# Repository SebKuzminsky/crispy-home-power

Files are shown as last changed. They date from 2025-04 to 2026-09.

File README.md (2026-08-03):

# Introduction

Project goals:
- When the PV system generates more energy than my house uses, store excess in batteries.
- When the house needs more energy that the PV system generates, supply from batteries.

This wants an "AC Coupled storage system".

Storing into batteries is easy, use an AC powered battery charger with
current control to charge the battery bank off the regular house AC.

How to supply from batteries?
- Large current-controlled micro-inverter?
- Multiple smaller micro-inverters, turn on/off as needed?

# Batteries

Manufacturer: American Battery Solutions

Product line: Alliance

Model: E48-2.0

Cell connections: 14S 8P

## Wire harness

Net      | Harness pin | Wire color
-------- | ----------- | ----------
Ign Low  | 2           | Blue (short to BAT- to ignite the battery)
CAN+ In  | 10          | Orange
CAN- In  | 9           | Black
CAN- Out | 7           | Purple
CAN+ Out | 6           | Gray

## CAN

Lots of good info in the Alliance User Manual.

There's an app in the `battery/` directory that controls the mode
and reports telemetry.

The modules collaborate over CAN to charge the low modules and discharge
the high modules in the expected way.  The following scope trace shows
the terminal voltage of three modules connected via CAN but not connected
via their high-voltage terminals.

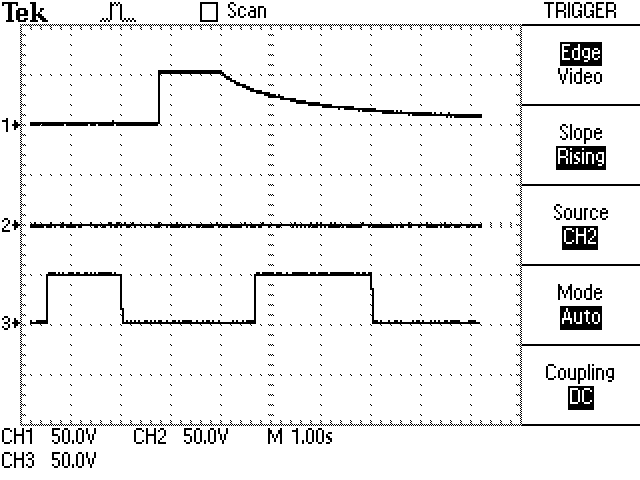
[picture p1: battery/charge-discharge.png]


- module on probe 1: ~51V
- module on probe 2: ~50V
- module on probe 3: ~48V

1. The pack starts out in "None" mode, where no modules are connected to the HV bus
2. I command the pack to Charge mode; the lowest-voltage module (on probe 3) enables its FET and connects to its HV terminals to receive charge.  The higher-voltage modules leave their FETs disabled and remain disconnected from the HV bus.
3. I command the pack to Drive/Discharge mode; the low module that was charging disconnects, and a second or so later the highest-voltage module (on probe 1) enables its FET and connects to the HV bus to discharge.
4. Switching back to Charge mode disables the high module and re-enables the low module.

Note that the middle module (50V, on probe 2) was never enabled in this
test.  If the low module had charged up to ~50V it would have enabled
during Charge mode, and if the high module had discharged down to ~50V
it would have enabled during Discharge/Drive mode.

```
CAN ID 0x502: `HOST_BatteryRequest`
    Payload: `HOST_stateRequest`, 1 byte
        0x00: None
        0x01: Drive/Discharge (power output)
        0x02: Charge (power input)
        0x03: Sleep
    Send this packet at 1 Hz
```

To ignite the battery from Linux over CAN and put it into Drive mode:
```
$ sudo ip link set can0 down
$ sudo ip link set can0 up type can bitrate 500000
$ while true; do cansend can0 '502#01.00'; sleep 1; done
```

To ignite the battery and put it into Charge mode, which makes it request
charge from the DeltaQ charger if it sees its CAN heartbeat:
```
$ while true; do cansend can0 '502#02.00'; sleep 1; done
```

To capture a CAN packet log:
```
$ candump -t a -l -f battery.candump can0
```

To replay a captured candump packet log:
```
$ sudo modprobe vcan
$ sudo ip link add dev vcan0 type vcan
$ sudo ip link set vcan0 up
$ canplayer -I battery.candump vcan0=can0
```

## Misc

Short the `IGN Low` pin to `BATT-` i think, and if the pack has
enough charge to boot the internal bms it'll energize `BATT+`.

Nathaniel says: I had one pack never shutoff after I turned it on with
an ignition signal, which is the main reason I no longer want to use
the pack BMS.

The HV terminals are tin-plated copper, with M8x1.25 thread, and should
be torqued to no more than 9Nm.

# Charger

Delta-Q
- Model: ICL 1500-058v
- Part number: 943-0016

## CAN

The one i have runs CAN at 500 kbps and uses different CAN packets than
what's in the docs.

CAN-H is blue
CAN-L is yellow

This makes it charge at 50 V, 2 A:
```
$ sudo ip link set can0 down
$ sudo ip link set can0 up type can bitrate 500000
$ while : ; do cansend can0 '30a#00.00.00.02.00.32.80.01'; cansend can0 '20a#00.31.01.00.32.20.00.01' ; sleep 1 ; done
```

The charger gets hot after a few minutes at higher current, but eventually
the fan comes on and cools it down.

# Inverters

I want a programmable inverter so I can tell it how much power to push
from the batteries to the home grid.

48V in, 240V split phase out

Bought a Victron inverter, model name "Phoenix". 48 V DC input, 120 VAC
output. 850 W continuous at 40°C, 2200W peak.

<https://www.victronenergy.com/inverters/phoenix-inverter-vedirect-250va-800va>

Works with an app on my phone, or you can get basic telemetry from a serial port.
`$ tio -b 19200 /dev/serial/by-id/usb-VictronEnergy_BV_VE_Direct_cable_VEAD75OS-if00-port0`

## Grid-forming

Grid-forming inverters supply voltage and frequency support to the grid,
as well as power.  This is needed for black start (bringing up the grid
after an outage).  Different modes of operation, such as: droop control,
virtual synchronous machine, hierachichal control, etc.

- PowerFlex 755T from Rockwell Automation
- Sunny Island from SMA Solar Technology
- PowerStore from ABB
- GridMaster from Ideal Power
- Victron Inverter Smart 48/2000, 230 VAC output

## Grid-following

Grid-following: supplies power, but must receive voltage and frequency from the grid.

## Misc info, open questions

Good info:
- <https://energycentral.com/c/iu/grid-forming-vs-grid-following>
- (terrible presentation) <https://www.youtube.com/watch?v=zWj21MMHPJc>
- <https://www.youtube.com/watch?v=RKQo9metcpU>

Some inverters can be both grid-forming and grid-following?

connecting inverters in parallel?  They must be grid-following, except
maybe one that "supplies voltage and frequency"?

Scenarios:
- grid tied
- grid tied system responds to grid disconnect
- island/off-grid (are these synonymous?)
- island reconnects to the grid
- black start

microgrids, islanded grids, large-scale grids

how does the enphase battery connect to the microgrid?  Does it go into the Combiner?

## Inverter Options

The internet thinks:
- "Enphase uses microinverters on their battery systems. They just stack them together."
- "With AC PV, the best options to power the entire main panel are EG4 18kPV, Midnite The One, or the Sol-Ark 15k. If you need more inverter, then parallel a 2nd or 3rd ..." <https://diysolarforum.com/threads/add-batteries-to-existing-solar-array-with-enphase-microinverters-and-iq-combiner.91153/post-1210119>

Inverters:
- Enphase M215/M250
    - <https://enphase.com/store/microinverters/legacy/m250-microinverter-kit>
- Enphase IQ8X-BATT
    - <https://enphase.com/download/iq8x-bat-microinverter-data-sheet>
    - Needs 52.5 VDC to start?
- Enphase IQ8+
    - runs on 16–58 V DC input
- Schneider Conext XW+ 6848
    - discontinuesd
- SunnyBoy
- Northern Electric BDM-600X
    - <https://northernep.com/downloads/technical-sheet/BDM-600X-Microinverter.pdf>

# Links & info

## Enphase Sunlight Backup

This is an Enphase design that keeps "limited loads" running when the
grid goes down, without battery storage.

- solar panels
- IQ8 micro-inverters with IQ8 cabling (this works with or without the grid when the needed additional equipment is present)
- IQ Combiner (includes IQ Gateway, solar production CT, 2 consumption CTs, enphase wireless comm kit)
- IQ System Controller (disconnects from the grid during outage)
- System shutdown switch
- Load center/subpanel (this is a subpanel that stays powered during outage)

## Misc

Probably do this: <https://university.enphase.com/?ccode=US&lang=en>

DIY Solar folks brainstorming a system very similar to what i want:
<https://diysolarforum.com/threads/adding-an-ess-to-enphase-enlighten-system.42737/>

<https://diysolarforum.com/threads/adding-diy-batteries-to-enphase-grid-tie-system.39487/>

<https://diysolarforum.com/threads/do-you-need-a-subscription-or-gateway-to-view-enphase-micro-inverter-data.92441/>

<https://diysolarforum.com/threads/using-solar-micro-inverters-with-batteries-instead-of-panels.8353/>

Enphase design guides: <https://enphase.com/installers/training/getting-started/design>

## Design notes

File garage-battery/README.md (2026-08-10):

This project is made from five parts:
1. Varta batteries
2. Victon inverter
3. Delta-Q charger (AC powered)
4. Enphase PV system
5. A Pi running the software in this repo

The batteries power the inverter, and the inverter powers a couple
of extension cords in the garage. The load is a fridge and a freezer,
the draw is about 200 W to 400 W.

# Software

The software in this repo monitors the SoC of the Varta batteries and
tries to keep them charged, using excess power from the PV array ideally
but falling back to grid AC power when needed.

## Varta Monitor

The Varta monitor looks at the Varta Master info, specifically the state
of charge and the charge request current.

## PV Monitor

The PV Monitor reads data from the Enphase Envoy via local Wifi (no
clown computing). Specifically we're looking to see if the PV system is
over-generating so we're exporting power to the grid.

## Control logic

The controller looks at the information gathered by the Varta Monitor
and the PV Monitor.  If the PV system is over-generating, we try to
divert this power to the batteries.

The Controller manages some internal configuration variables:
* minimum SoC: Take action when the batteries get below this.
* max SoC: Do not charge the batteries above this.
* charge current: Try to charge the batteries at this rate.

The Control logic works like this:

- When the house is generating excess power we set min SoC to 75%, max
  SoC to 80%, and "available current" sufficient to absorb most of the
  exported power.

- When there is no power being exported we set a min SoC of 20%, max
  SoC of 25%, and "available current" to infinity.

If the battery SoC is above the max SoC, we request the Charger to turn off.

If the battery SoC is below the min SoC, we request the Charger to turn
on. The charge current is the minimum of "available current" computed
above an the Varta charge request current.

## Charge controller

The charge controller just drives the Delta-Q charger as specified by
the Control logic.

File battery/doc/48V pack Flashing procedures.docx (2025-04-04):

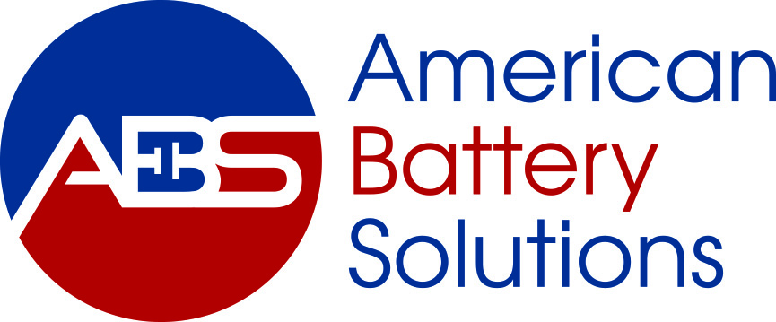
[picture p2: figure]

48V pack core module SW flashing procedures

SW flashing hardware needed: PEAK CAN USB dongle.

Setup (first time only)

1. Safe the Flashing Environment:

Download and save the flashing environment on the desktop or location of your choice. This should have been provided from ABS via flash drive or drop box link

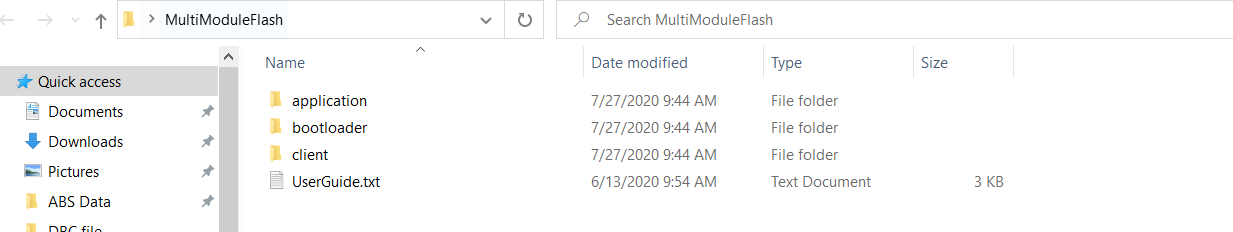
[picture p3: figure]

2. Install the Peak USB-CAN drivers:

https://www.peak-system.com/quick/DrvSetup

3. Install Bus Master:

(this is optional but allows you to see CAN traffic and read variables with the appropriate .dbf file)

https://rbei-etas.github.io/busmaster/download.html

4. Connect the Peak USB-CAN dongle

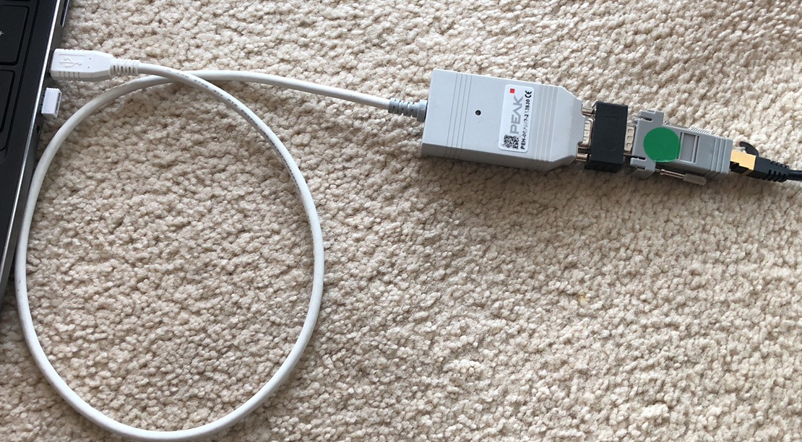
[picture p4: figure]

Ethernet cable to battery

120 ohm Termination

RJ45 – DB9 adapter

Peak USB-CAN Dongle

Flashing steps:

Step 1: Make Connection

Connect ONE Alliance Module external LV connector to the black or white ethernet splitter with an ethernet cable. Put the gold termination Ethernet connection into the empty space on splitter

Step 2: Ensure correct Software is flashed

In the flashing environment from the Setup section above, go to the folder Client\Hex and find the correct software to flash and copy it. The nomenclature for the software versions is the last digit indicated how many modules are configured. Below is an example of version 11 with 2 modules.

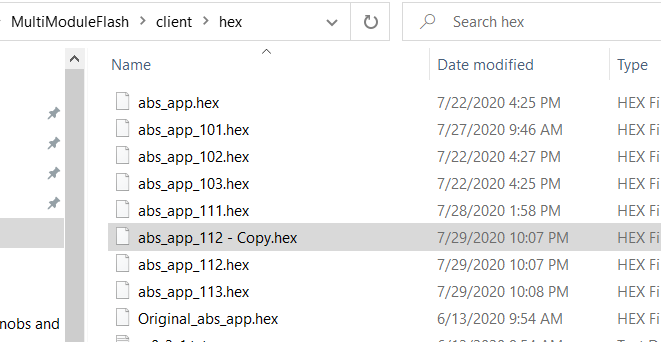
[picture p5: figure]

Delete the file abs_app.hex

Rename abs_app_112 – Copy.hex to abs_app.hex. The flashing tool will flash whatever software is called abs_app.hex

Step 3: Ensure battery is NOT in Drive or Charge

If using the ABS Development Display, Ensure battery is NOT in Drive or Charge. The Battery Status should indicate either Sleep, Standby, or Standby – Not Ready.

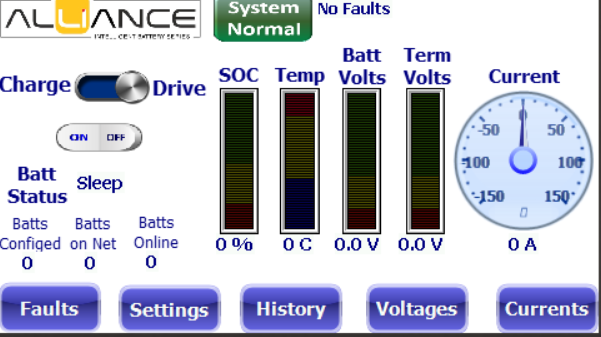
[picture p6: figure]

If NOT using the ABS Development Display, ensure the Ign- is OFF and the terminals do not have any voltage

Step 4: Flash the battery

Go to the folder: \client\windows_scripts and double click on the abs_program.app. There could be windows warning, just accept them and proceed

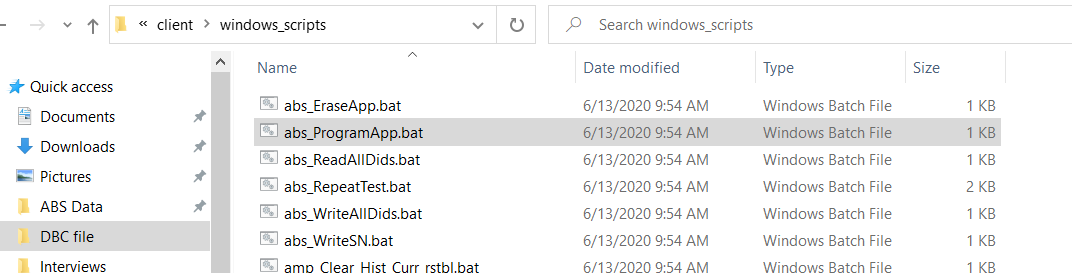
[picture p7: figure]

Step 3: Flashing:

Then the flashing script will run and automatically erase the old program and start flashing the new program to the BMS board. If it fails initially, go back to step 3 and ensure the battery is not in Drive or

Step 4: Update Instance ID:

If you are changing the number of modules in the pack, you will need to update the instance ID. This is the ID of the module in the pack, ie 0, 1, or 2 for a 3 module configuration. If the number of modules being configured is unchanged you may skip this step.

In the Windows_Script folder find the batch file for Update_Instance_IDx. All Instance ID’s must be unique. For the first module update with Instance0. You should get a “positive response” from the updater. If you don’t get the positive response, repeat until you do.

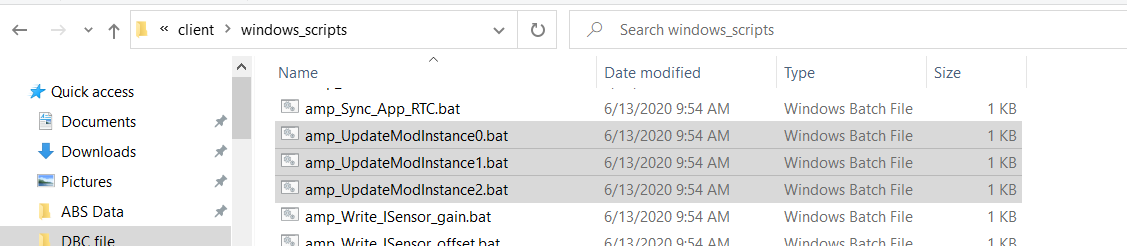
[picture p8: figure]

Step 5: Update additional modules:

Move the Alliance LV connector to the next module that you want to update and repeat steps 3 and 4 as appropriate until all modules have been updated.

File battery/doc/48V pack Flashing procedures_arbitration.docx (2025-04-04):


48V pack core module SW flashing procedures

SW flashing hardware needed: PEAK CAN USB dongle.

Setup (first time only)

1. Save the Flashing Environment:

Download and save the flashing environment on the desktop or location of your choice. This should have been provided from ABS via email/flash drive/drop box link


2. Install the Peak USB-CAN drivers:

https://www.peak-system.com/quick/DrvSetup

3. Install Bus Master:

(this is optional but allows you to see CAN traffic and read variables with the appropriate .dbf file)

https://rbei-etas.github.io/busmaster/download.html

4. Connect the Peak USB-CAN dongle


Ethernet cable to battery

120 ohm Termination

RJ45 – DB9 adapter

Peak USB-CAN Dongle

APP SW Flashing steps:

Step 1: Make Connection

Connect ONE Alliance Module external LV connector to the black or white ethernet splitter with an ethernet cable. Put the gold termination Ethernet connection into the empty space on splitter

Step 2: Ensure correct Software is flashed

In the flashing environment from the Setup section above, go to the folder client\hex and find the correct software to flash

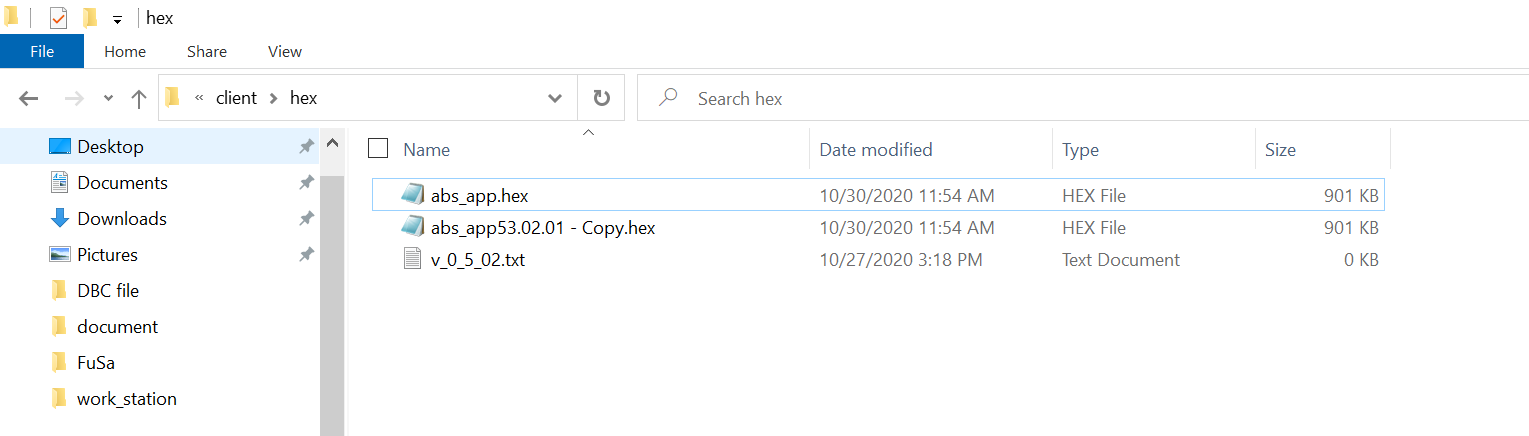
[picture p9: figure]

The flashing tool will flash whatever software is called abs_app.hex, if you have a new hex file release, go to this folder, delete the old one, and rename the new one to be abs_app.hex

Step 3: Ensure battery is NOT in Drive or Charge

Make sure the FETs are open and the pack terminal is not energized

Step 4: Flash the battery

If you need to update the bootloader, then go to the “Bootloader update steps” procedures to update the bootloader first before flashing the application software, if bootloader update not needed, then go to the folder: \client\windows_scripts and double click on the “abs_ProgramApp.bat”. There could be windows warning, just accept them and proceed. Please refer below compatibility matrix table to see if the bootloader needs to be updated for the SW you are going to flash:

Bootloader version | App SW version < V4 | App SW version >= V4
0.0.4 | Yes | No
0.1.2 | No | Yes
0.1.3 | No | Yes

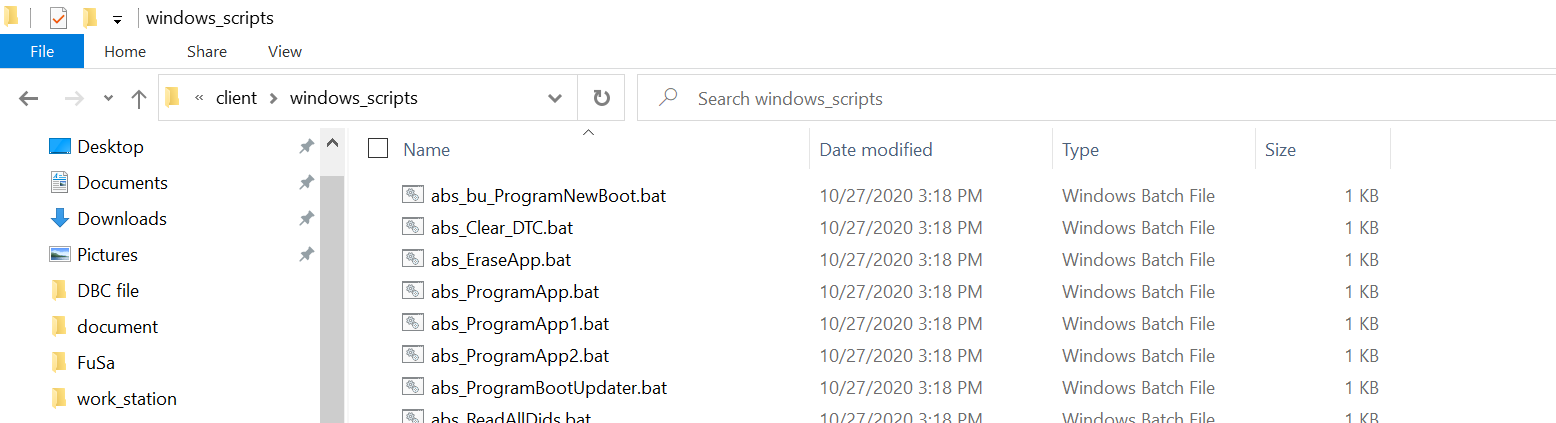
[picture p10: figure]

Step 5: Flashing

Then the flashing script will run and automatically erase the old program and start flashing the new program to the BMS board. If it fails initially, try it again right after it, it might be caused by the timeout fault while BMS was in sleep for the first time, normally it takes two times to successfully program it, or go back to step 3 and ensure the battery is not in Drive or charge

Step 6: Arbitration (for multi_module application)

If you are flashing App software versions >= V5 and >= 2 modules connected in parallel, then please refer to the “Node ID Arbitration steps” to automatically flash the instance ID to each module for the multi-module configuration

Bootloader update steps (PEAK CAN dongle needed):

Step 4.1: go to the boot_updater - > windows_scripts

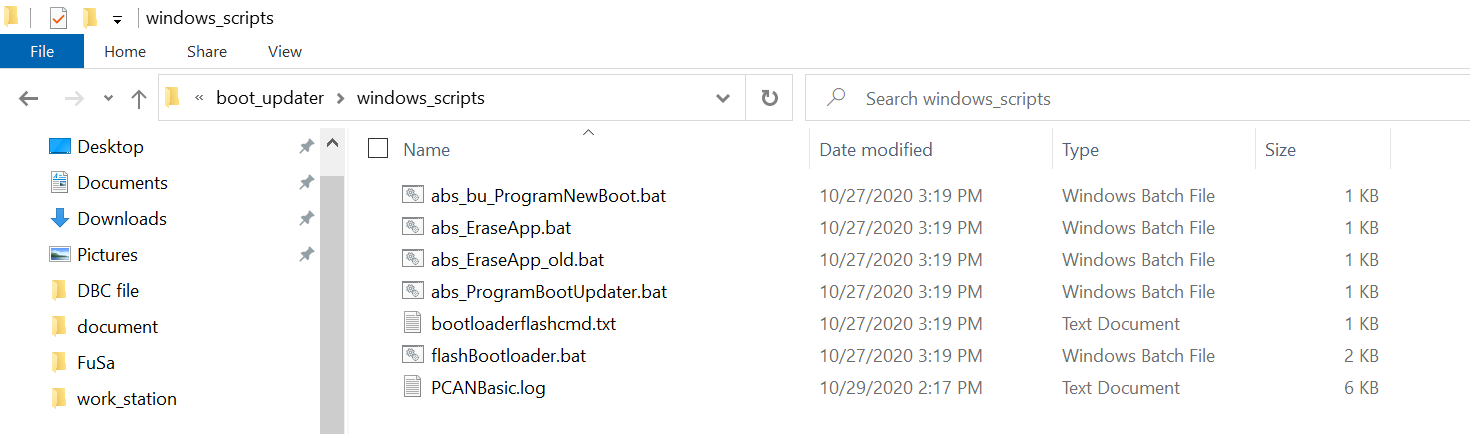
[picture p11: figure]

Step 4.2: double click “abs_EraseApp.bat" to erase the old app software, and only let the bootloader running, you shall see a message showing the process done

Step 4.3: double click “abs_ProgramBootUpdater.bat", to load the updater for the new bootloader

Step 4.4: double clock “abs_bu_ProgramNewBoot.bat" to load the new bootloader

Node ID Arbitration steps:

Step 6.1: Serial number flashing

This step needs PEAK CAN dongle, go to folder: \client\windows_scripts, right click “abs_WriteSN.bat” to edit the S/N and flash the serial number to the modules

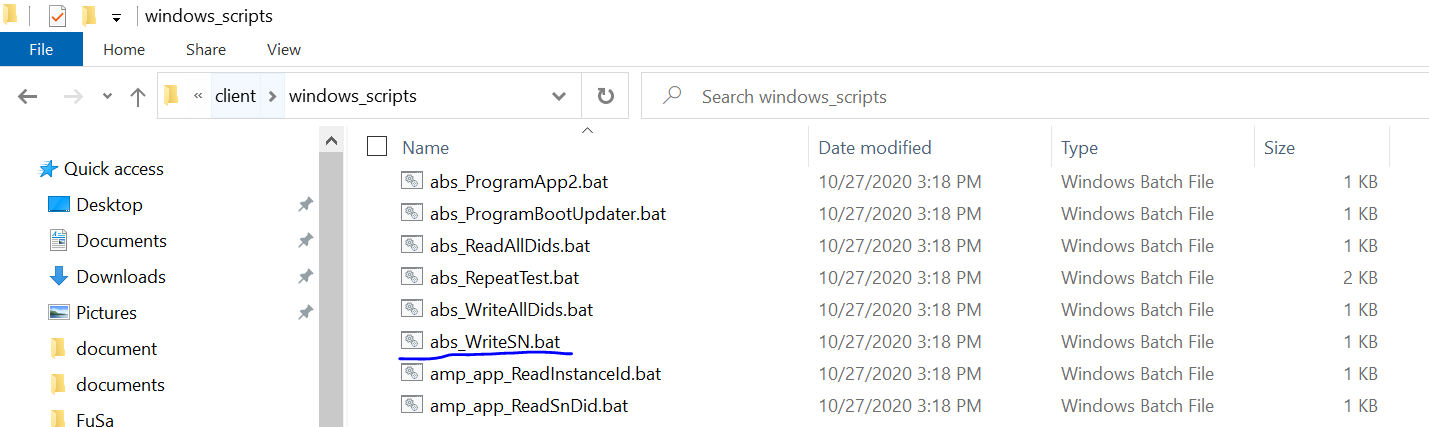
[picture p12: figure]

Please use below format to edit the S/N in the batch file (19 digits for the S/N following 13 digits “0” s):

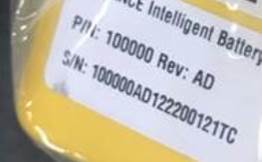
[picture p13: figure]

Replace "12345678901234567890123456789012" with "1000001222001210000000000000"

Then save, close the editor, double click” “abs_WriteSN.bat” to flash the S/N to the modules, this has to be done one by one for the modules.

Step 6.2: Arbitration (comparing S/N number and automatically write instance ID to the modules)

Step 6.2.1:

Wakeup the modules by sending the signal HOST_stateRequest = 0 cyclically (Busmaster /CANalyzer, or other CAN tools) and make sure the module in standby mode

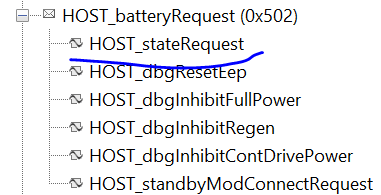
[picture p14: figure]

Step 6.2.2:

Send out the HOST_nodeRequest message manually (make sure it is not cyclic messages)

Configure the signals in HOST_nodeRequest like below:

HOST_startNodeId = 1

HOST_enablePFlashWrite = 1

HOST_cmdNumExpectedNodes = 6

HOST_securityKey = A3A3A3/10724259 (depends on using hex number / decimal number)

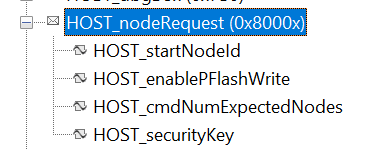
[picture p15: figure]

Normally it will not work for just one time, a few times manual send retrial needed before successfully arbitrate the modules (better wait around 2 minutes between each retrial), if below signal BATT_packState change from 0 to 1 (standby not ready to standby ready), that means the process had been completed. Please stop sending the HOST_nodeRequest message after the process complete.

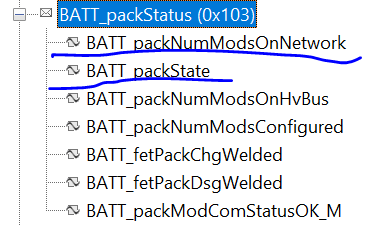
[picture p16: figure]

Also, the BATT_packNumModsOnNetwork will be equal to the HOST_cmdNumExpectedNodes if the process successfully completed

Step 6.2.3 (optionally, if step 6.2.2 fails):

Ideally, step 6.2.1 and step 6.2.2 shall complete the arbitration process, but since there is bug in V5 software (this bug will be fixed in V6 SW), normally it will not work directly with the HOST_cmdNumExpectedNodes > 2, if step 6.2.2 fails, then please do it incrementally, for example, if 6 modules configuration is needed, then repeat step 6.2.1 and step 6.2.2 following incremental order 2 -> 3 -> 4 -> 5 -> 6, and modify the HOST_cmdNumExpectedNodes number accordingly:

- Connect 2 modules, and follow step 6.2.1 and 6.2.2,

HOST_cmdNumExpectedNodes = 2

- Add one module, totally 3 modules, and follow step 6.2.1 and 6.2.2, HOST_cmdNumExpectedNodes = 3
- Add one module, totally 4 modules, and follow step 6.2.1 and 6.2.2, HOST_cmdNumExpectedNodes = 4
- Add one module, totally 5 modules, and follow step 6.2.1 and 6.2.2, HOST_cmdNumExpectedNodes = 5
- Add one module, totally 6 modules, and follow step 6.2.1 and 6.2.2, HOST_cmdNumExpectedNodes = 6

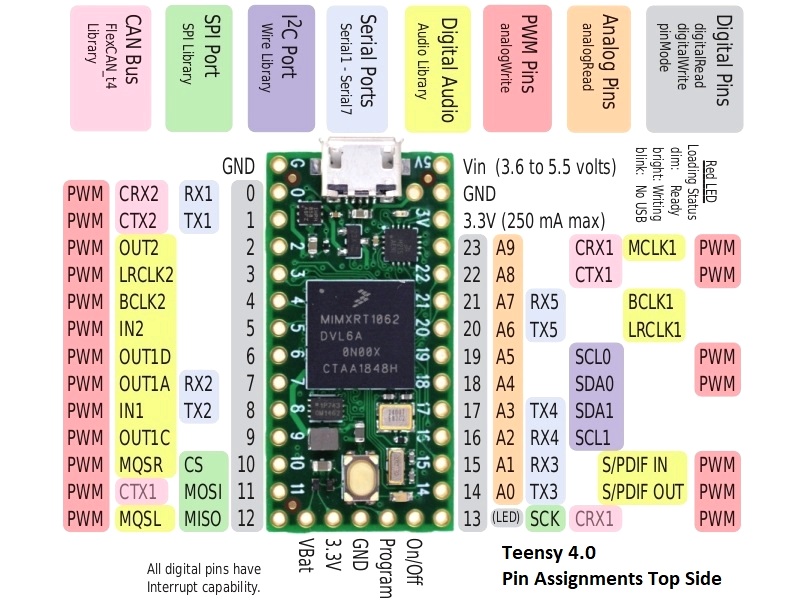
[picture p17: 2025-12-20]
teensy-battery-controller/doc/Teensy-4.0-Pinout-Top.jpg

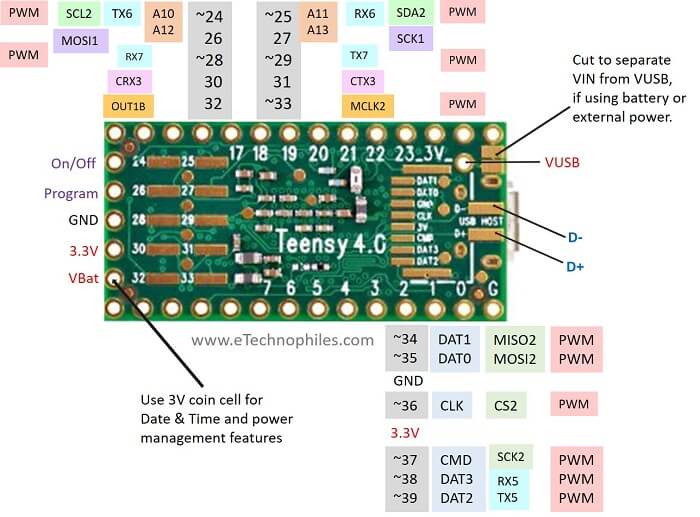
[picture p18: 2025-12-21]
teensy-battery-controller/doc/Teensy-4.0-Back-view.jpg

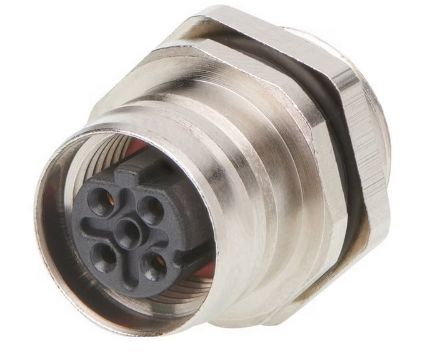
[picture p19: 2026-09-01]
varta-can-ignition-enclosure/wire-harness/m12-5.png

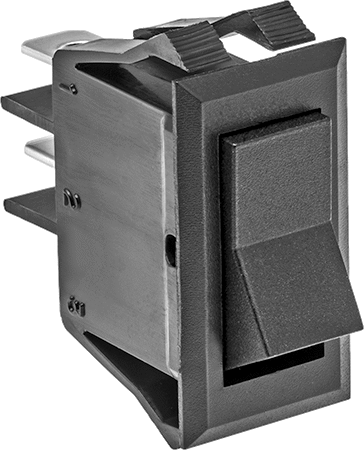
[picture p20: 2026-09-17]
varta-can-ignition-enclosure/wire-harness/rocker-switch.png

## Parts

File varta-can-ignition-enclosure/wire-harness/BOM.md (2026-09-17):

1x Rocker switch: <https://www.mcmaster.com/7395K11/>
3x M12-5 Connectors: <https://www.amazon.com/Lonlonty-Aviation-Connector-Waterproof-Threaded/dp/B0BBQR9FD1>
2x Wago connectors (lever lock), 3 position
2x Wago connectors (lever lock), 4 position
Wire, 24 AWG (black, yellow, white, green)
14x Wire ferrule, 24 AWG
8x M3 threaded insert: <https://www.mcmaster.com/94180A331/>
8x M3-10 SHCS: <https://www.mcmaster.com/91290A115/>

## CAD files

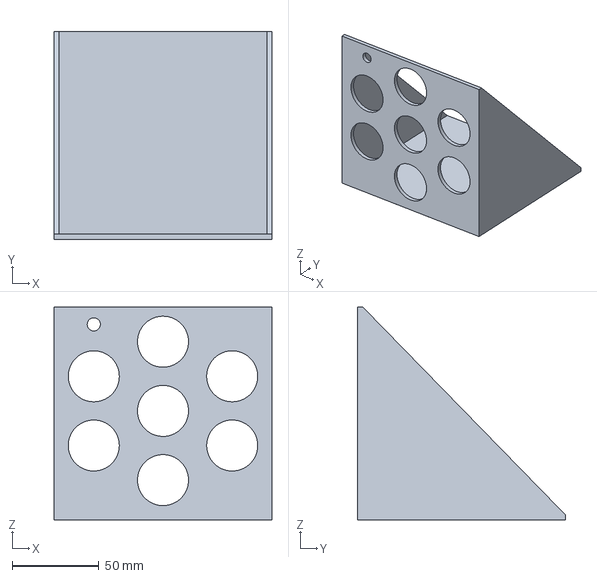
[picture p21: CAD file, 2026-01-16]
abs-battery-enclosure/faceplate.FCStd
126.0 x 120.0 x 123.0 mm

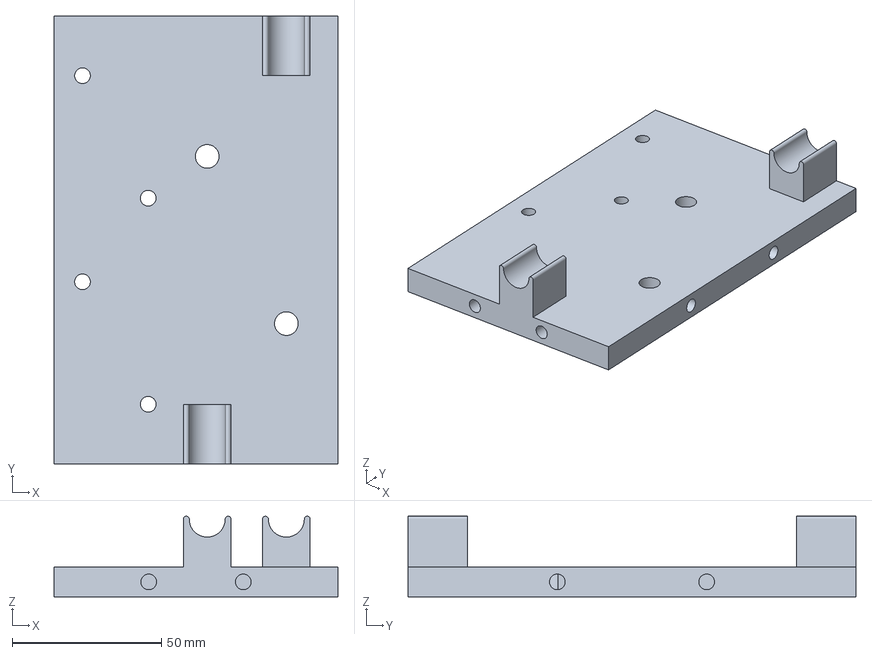
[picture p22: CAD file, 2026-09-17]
precharge-enclosure/precharge-plate.3mf
95.0 x 150.0 x 27.0 mm

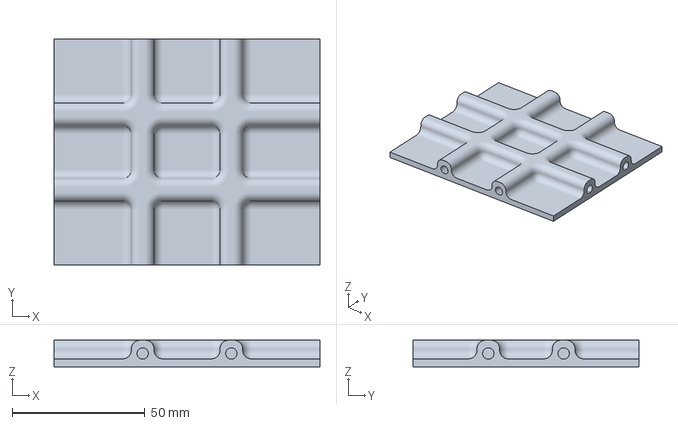
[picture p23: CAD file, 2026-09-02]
varta-can-ignition-enclosure/can-ignition-plate.3mf
100.0 x 85.0 x 10.0 mm

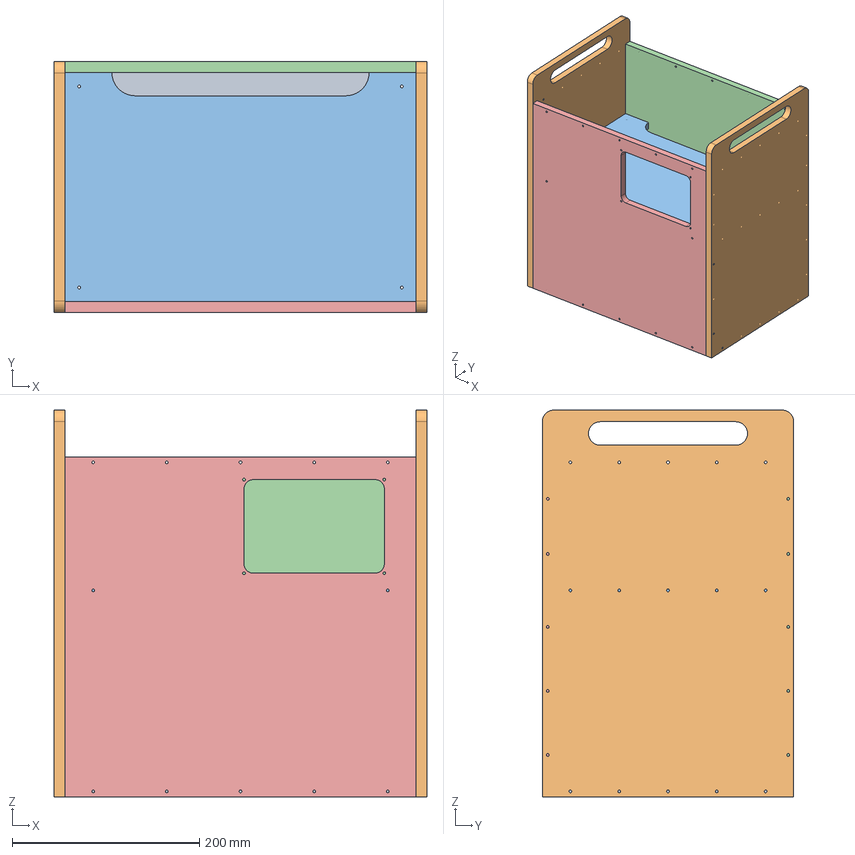
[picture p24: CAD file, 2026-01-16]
abs-battery-enclosure/box.FCStd
398.7 x 268.7 x 413.6 mm
top_bottom x 2
side x 2
shelf_with_cutout
back
front

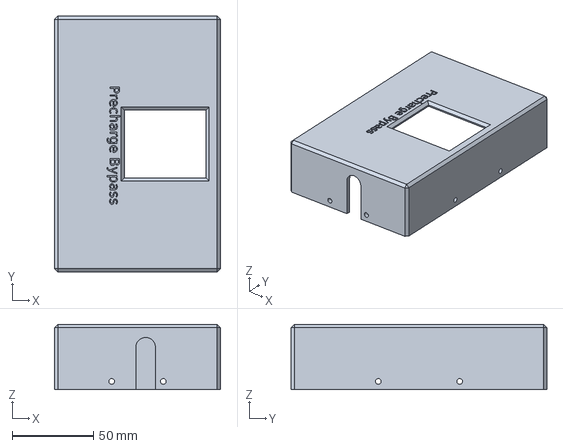
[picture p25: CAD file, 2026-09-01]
precharge-enclosure/precharge-lid.3mf
102.0 x 157.0 x 40.0 mm

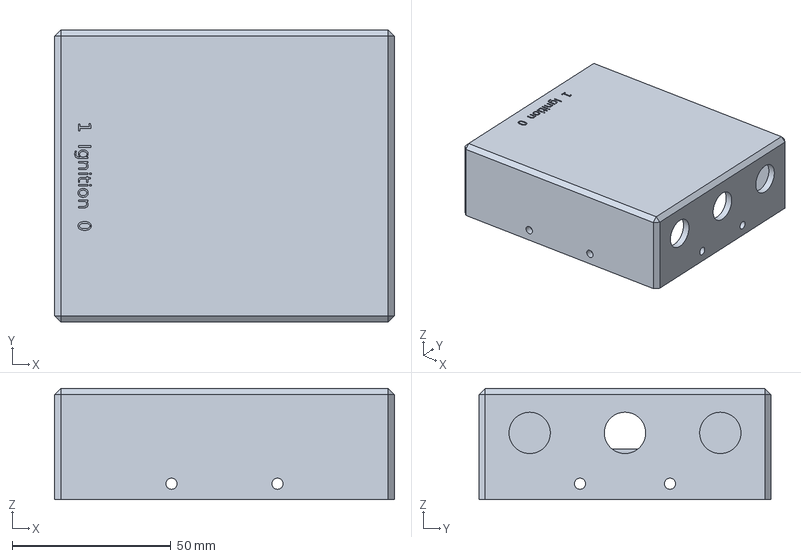
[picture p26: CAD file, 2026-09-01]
varta-can-ignition-enclosure/can-ignition-lid.3mf
107.0 x 92.0 x 35.0 mm

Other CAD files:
precharge-enclosure/precharge-enclosure.FCStd
varta-can-ignition-enclosure/can-ignition-enclosure.FCStd

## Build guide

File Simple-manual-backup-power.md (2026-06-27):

# Introduction

This is a simple backup power system, basically a big USB battery.

The main use case is providing a bunch of USB chargers during brief
(1-2 day) power outages and car camping trips.

## Goals

### Requirements

1. Several (5+?) USB-PD outputs.

2. At least one USB output powerful enough to charge my laptop and run
   my Pinecil (20V, 100W).

3. Simple to use.
    - easy to turn on/off
    - big E-stop button on top?
    - somewhat easy to charge

### Optional stretch goals

1. 1 kW of AC output.

2. A bunch of 12V car cigarette outlets, for plugging in more USB chargers
   and my NiteCore AA/AAA charger.

3. PV charging!

### Design considerations

I've found one 48V DC to USB adapter, and it's pretty low power, only 30W
(12V, 2.5A). This satisfies Requirement 1 but not 2.

It's easy to find 12V to 100W USB adapters, from the automobile market,
though i don't know about efficiency of this option?

So maybe make 300+ W of 12V, and run some of it to one or two of these
100W car USB chargers.

For charging: mount a DeltaQ inside, with the AC cord hanging out the
back. Charge whenever the AC is plugged in. FIXME: Or maybe mount the
charger outside the battery box, at a fixed charging station, so you
can move the battery around more easily?

## Components

* a bunch of ABS Alliance E48-2.0 batteries

* a Delta-Q charger

* a little embedded system to control it via CAN and provide telemetry
  via a little screen or a web page or some LEDs

* a plywood enclosure that can be moved around with a hand truck

* some kind of inverter (FIXME, optional)

# Development phases

## Phase 0 - Done

Run battery and charger from laptop, each on a dedicated CANBUS, manual
software. Proof of concept, but awkward to use.

## Phase 1 - Done

- Teensy controls battery
- Teensy powered from HV bus via Buck90 set to output 5V
- CAN to battery only, no automatic charger control
- Momentary push button to turn on: short Battery Ign to Bat-, ignites one module, then the others wake by CAN
- Use the same momentary push button to turn off: short a GPIO to Gnd
- USB for debugging (FIXME: awkward, teensy doesn't like simultaneous USB and external power, use caution)
- Use existing 48v to USB 30W adapters (fused)

The battery ignites if i connect Bat Ign to a Teensy GPIO, even if the
teensy is powered by the Buck90 and everything is powered down. Looks
like there's some coupling between the GPIOs and Gnd on the powered-off
MCU, so i'm using a diode to prevent current flowing into the gpio.

I'm powering the Teensy using a Buck90 DC-DC converter, with Vin
connected to the battery HV terminals, the pot dialed so Vout is 5V,
and Vout connected to Teensy Vin. This works well as long as i dont
connect a computer to the Teensy USB port.

There's a pad on the underside of the Teensy that you can cut to power
it by Vin and still use USB, but i don't want to modify the Teensy and i
want to be able to still power it from USB, so i can program the Teensy
without turning on the battery.  I think this means i should put a kill
switch in the power line between the buck and the teensy, and remember
to use it wheneve i plug in USB.

## Phase 2 - In progress

### Done
- Add 240W 48V-to-12V buck
- Add 12V power distribution
- Add a bunch of 12v car outlets (each individually fused)
- Add 100W USB PD outlets

### To do
- Build an enclosure
    - Done
        - 11.85 mm thick birch plywood
        - ~2800 mm/min cutting feed for 1/2" 2 fl Carbide, 7 mm doc, slotting
        - use rough and finishing cuts
        - predrill, don't just countersink, and use holes for work holding
        - front is upside down in CAM
        - update countersink diameters
        - shelves too small for battery :-(
            - front-to-back: 241
        - front window too small
    - To do
        - sigh, add 25 mm for the factory battery LV connectors or slightly more for the digikey ones
        - the shelves should sit in a little slot in the front/back/sides
          to help align everything during assembly, cut slightly oversized
          because i'm using a larger diameter endmill
        - my clamps are too small, need 16" jaws at least, 4x, hackspace has them
        - front should have 5x holes for shelf, back has 2 like now
            - cutout on shelf towards rear
- add some kind of charging support
    - charger is heavy and bulky, should live outside the battery box
      and be connected only as needed
    - add 48V 20A panel-mount input from charger
        - Anderson SBxxx (available in 50-350 Amp, 50 A/2.5 kW is probably good), 6 or 8 AWG wire
        - anderson powerpole 15/45, 10 AWG wire
            - Blue to indicate 48 V
            - <https://www.printables.com/model/1355413-anderson-powerpole-panel-mount>
    - how to control charging?
        - add a CAN connection from the teensy to charger, let the teensy control charging?
        - add a CAN connection from battery to charger, let the batteries control charging?
        - control charging from laptop?
    - i think it's *possible* to charge while in Discharge mode,
      but i think it'll charge the highest-voltage modules, not the
      lowest-voltage ones
    - add some kind of UI to initiate charging?
        - keep the on/off button as it is now
        - add a SPDT toggle-switch to select Discharge or Charge mode
            - each throw connect a different GPIO to ground so the MCU knows
        - Or, MCU detects the charger via heartbeat on second MCU CAN
          input, switches automatically to charge mode?
    - DB9 for CAN between Charger and Teensy
    - need some indicator to user when charging's done
- Move from breadboard to something more permanent
    - better LV wiring, got solder cup connectors from digikey

### Maybe do
- Add power indicator LEDs (48V and 12V)
- Add 48V power distribution?
    - add panel mount Anderson PP or SB connectors for HV bus, usable by charger and inverter etc
- add a little screen showing Charge/Discharge mode, voltage, current, soc

## Future work

Add an inverter. Grid-forming (stand-alone, not connected to the grid
or to other inverters) is fine for this application. 120 VAC, 1300 W
_continuous_ would run each of my fridges & freezers in turn, and a
beefy electric heater when needed.

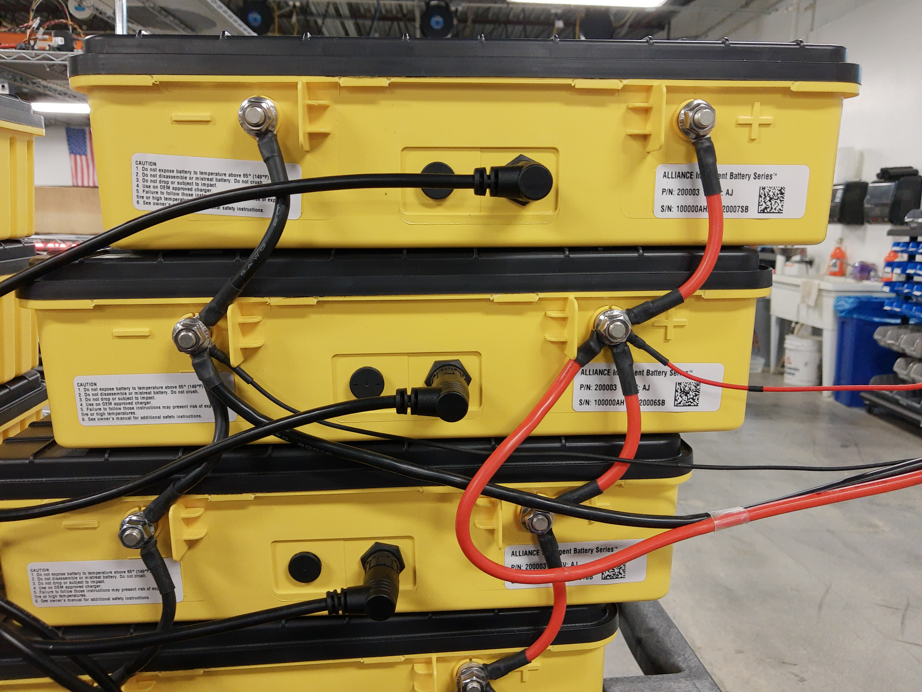
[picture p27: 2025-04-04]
battery/doc/wiring-example.jpg

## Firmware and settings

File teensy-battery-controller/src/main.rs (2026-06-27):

//! The starter code slowly blinks the LED and sets up
//! USB logging. It periodically logs messages over USB.

#![no_std]
#![no_main]

mod abs_alliance_can_messages;
mod debounced_input_pin;
mod delta_q_can_messages;

use teensy4_panic as _;

#[derive(Clone, Debug, PartialEq)]
pub enum ControllerMode {
    /// The controller is booting, wait for the user to release the power button then go to
    /// Discharge mode.
    Booting,

    /// HV bus is on and providing power.
    Discharge,

    /// User has requested the battery turn off (de-energize HV bus).
    Sleep,
}

#[rtic::app(device = teensy4_bsp, peripherals = true, dispatchers = [KPP])]
mod app {
    use bsp::board;
    use teensy4_bsp as bsp;

    use imxrt_log as logging;

    // If you're using a Teensy 4.1 or MicroMod, you should eventually
    // change 't40' to 't41' or micromod, respectively.
    use board::t40 as my_board;

    use rtic_monotonics::systick::{Systick, *};

    use embedded_can::Frame;
    use embedded_hal::digital::InputPin;

    /// There are no resources shared across tasks.
    #[shared]
    struct Shared {
        /// The CAN1 interface on pins 22 (Tx) and 23 (Rx), connected
        /// to the ABS Alliance battery pack.
        can1: board::Flexcan1,

        /// The CAN2 interface on pins 1 (Tx) and 0 (Rx), connected to
        /// the Delta-Q charger.
        can2: board::Flexcan2,

        /// The current mode.
        controller_mode: crate::ControllerMode,
    }

    /// These resources are local to individual tasks.
    #[local]
    struct Local {
        /// The LED on pin 13.
        led: board::Led,

        /// Power button, pulls down when pressed.
        power_button_gpio: crate::debounced_input_pin::DebouncedInputPin<
            teensy4_bsp::hal::gpio::Input<teensy4_bsp::pins::t40::P2>,
        >,

        /// A poller to control USB logging.
        poller: logging::Poller,
    }

    #[init]
    fn init(cx: init::Context) -> (Shared, Local) {
        let board::Resources {
            mut gpio2,
            mut gpio4,
            mut pins,
            usb,
            flexcan1,
            flexcan2,
            ..
        } = my_board(cx.device);

        let led = board::led(&mut gpio2, pins.p13);
        let poller = logging::log::usbd(usb, logging::Interrupts::Enabled).unwrap();

        let mut can1 = board::flexcan(flexcan1, pins.p22, pins.p23);
        can1.set_baud_rate(500_000);
        can1.set_max_mailbox(16);
        can1.disable_fifo();

        let mut can2 = board::flexcan(flexcan2, pins.p1, pins.p0);
        can2.set_baud_rate(500_000);
        can2.set_max_mailbox(16);
        can2.disable_fifo();

        const PIN_CONFIG: bsp::hal::iomuxc::Config = bsp::hal::iomuxc::Config::zero()
            .set_pull_keeper(Some(bsp::hal::iomuxc::PullKeeper::Pullup100k));
        bsp::hal::iomuxc::configure(&mut pins.p2, PIN_CONFIG);
        let power_button_gpio =
            crate::debounced_input_pin::DebouncedInputPin::new(gpio4.input(pins.p2), 10);

        let controller_mode = crate::ControllerMode::Booting;

        Systick::start(
            cx.core.SYST,
            board::ARM_FREQUENCY,
            rtic_monotonics::create_systick_token!(),
        );

        blink::spawn().unwrap();
        battery_can_rx_task::spawn().unwrap();
        battery_can_tx_task::spawn().unwrap();
        charger_task::spawn().unwrap();
        power_button_task::spawn().unwrap();

        (
            Shared {
                can1,
                can2,
                controller_mode,
            },
            Local {
                led,
                power_button_gpio,
                poller,
            },
        )
    }

    #[task(local = [led], shared = [controller_mode])]
    async fn blink(context: blink::Context) {
        let led = context.local.led;
        let mut controller_mode = context.shared.controller_mode;
        loop {
            led.toggle();

            let delay_ms = match controller_mode.lock(|mode| mode.clone()) {
                crate::ControllerMode::Booting => 100,
                crate::ControllerMode::Discharge => 250,
                crate::ControllerMode::Sleep => 500,
            };
            Systick::delay(delay_ms.millis()).await;
        }
    }

    #[task(local = [power_button_gpio], shared = [controller_mode])]
    async fn power_button_task(context: power_button_task::Context) {
        let power_button_gpio = context.local.power_button_gpio;
        let mut controller_mode = context.shared.controller_mode;
        let mut prev_button_state = power_button_gpio.is_high().unwrap();

        loop {
            let button_state = power_button_gpio.is_high().unwrap();
            let button_was_pressed = prev_button_state && !button_state;
            let button_was_released = !prev_button_state && button_state;

            controller_mode.lock(|mode| {
                match mode {
                    crate::ControllerMode::Booting => {
                        // The Booting state is the only one that cares
                        // about the rising edge of the gpio (the release
                        // of the button).
                        if button_was_released {
                            *mode = crate::ControllerMode::Discharge;
                        }
                    }
                    crate::ControllerMode::Discharge => {
                        if button_was_pressed {
                            *mode = crate::ControllerMode::Sleep;
                        }
                    }
                    crate::ControllerMode::Sleep => {
                        if button_was_pressed {
                            *mode = crate::ControllerMode::Discharge;
                        }
                    }
                }
            });

            prev_button_state = button_state;

            // FIXME: lame polling loop, switch to interrupts
            Systick::delay(10.millis()).await;
        }
    }

    #[task(shared = [can1])]
    async fn battery_can_rx_task(context: battery_can_rx_task::Context) {
        let mut can = context.shared.can1;

        loop {
            // Process any incoming CAN packets that have arrived.
            match can.lock(|can| can.read_mailboxes()) {
                Some(data) => {
                    // TODO: get rid of this and make it a "real" message
                    let frame_id = data.frame.id();
                    let id = match frame_id {
                        imxrt_hal::can::Id::Standard(v) => v.as_raw().into(),
                        imxrt_hal::can::Id::Extended(v) => v.as_raw(),
                    };
                    if id == 292 || id == 261 {
                        // Decode the CAN message
                        if let Some(payload) = data.frame.data() {
                            match crate::abs_alliance_can_messages::Messages::from_can_message(
                                data.frame.id(),
                                payload,
                            ) {
                                Ok(msg) => {
                                    // log::info!("{:#?}", msg);
                                    match msg {
                                        crate::abs_alliance_can_messages::Messages::BattPackSoc(m) => {
                                            log::info!("User SoC={:?}%", m.batt_pack_user_soc_raw());
                                            log::info!("SoC={:?}%", m.batt_pack_soc_raw());
                                        }
                                        crate::abs_alliance_can_messages::Messages::BattPackHvStatus(m) => {
                                            log::info!("Vpack={:?} V", m.batt_v_pack());
                                            log::info!("Ipack={:?} A", m.batt_i_pack_filtered());
                                        }
                                        _ => {
                                            // unknown/unhandled message
                                        }
                                    }
                                }
                                Err(e) => log::error!("{e:?}"),
                            }
                        }
                    }
                }
                None => {
                    // No CAN packets to read, sleep and poll again.
                    // FIXME: switch to nonblocking interrupt-driven mode
                    Systick::delay(5.millis()).await;
                }
            }
        }
    }

    fn battery_send_host_state_request<C>(
        can: &mut C,
        state: crate::abs_alliance_can_messages::HostBatteryRequestHostStateRequest,
    ) where
        C: embedded_can::nb::Can,
    {
        let host_battery_request = crate::abs_alliance_can_messages::HostBatteryRequest::new(
            false,
            false,
            false,
            false,
            false,
            state.into(),
        )
        .unwrap();
        log::info!("sending {:#?}", host_battery_request);

        match &embedded_can::Frame::new(host_battery_request.id(), host_battery_request.data()) {
            Some(frame) => match can.transmit(frame) {
                Ok(_) => (),
                Err(e) => {
                    log::error!("error sending CAN Frame: {:#?}", e);
                }
            },
            None => {
                log::error!("error making CAN Frame from {:#?}", host_battery_request);
            }
        }
    }

    #[task(shared = [can1, controller_mode])]
    async fn battery_can_tx_task(context: battery_can_tx_task::Context) {
        let mut can = context.shared.can1;
        let mut controller_mode = context.shared.controller_mode;

        let mut battery_is_sleeping = false;

        // During normal operation: Once per second, send the "Drive" command to the battery pack.
        loop {
            let mode = controller_mode.lock(|mode| mode.clone());
            match mode {
                crate::ControllerMode::Booting => {
                    battery_is_sleeping = false;
                    can.lock(|can| battery_send_host_state_request(can, crate::abs_alliance_can_messages::HostBatteryRequestHostStateRequest::Drive));
                }
                crate::ControllerMode::Discharge => {
                    battery_is_sleeping = false;
                    can.lock(|can| battery_send_host_state_request(can, crate::abs_alliance_can_messages::HostBatteryRequestHostStateRequest::Drive));
                }
                crate::ControllerMode::Sleep => {
                    // The ABS Alliance batteries only tolerate one
                    // Sleep command, a second packet wakes them back up.
                    if !battery_is_sleeping {
                        can.lock(|can| battery_send_host_state_request(can, crate::abs_alliance_can_messages::HostBatteryRequestHostStateRequest::Sleep));
                        battery_is_sleeping = true;
                        log::info!("putting battery to sleep");
                    }
                }
            };


            Systick::delay(1000.millis()).await;
        }
    }

    #[task(shared = [can2])]
    async fn charger_task(context: charger_task::Context) {
        let mut can = context.shared.can2;

        loop {
            // Process any incoming CAN packets that have arrived.
            match can.lock(|can| can.read_mailboxes()) {
                Some(data) => {
                    // TODO: get rid of this and make it a "real" message
                    let frame_id = data.frame.id();
                    let id = match frame_id {
                        imxrt_hal::can::Id::Standard(v) => v.as_raw().into(),
                        imxrt_hal::can::Id::Extended(v) => v.as_raw(),
                    };

                    // Decode the CAN message
                    if let Some(payload) = data.frame.data() {
                        match crate::delta_q_can_messages::Messages::from_can_message(
                            data.frame.id(),
                            payload,
                        ) {
                            Ok(msg) => {
                                log::info!("{:#?}", msg);
                            }
                            Err(e) => log::error!("{e:?}"),
                        }
                    }
                }
                None => {
                    // No CAN packets to read, sleep and poll again.
                    // FIXME: switch to nonblocking interrupt-driven mode
                    Systick::delay(5.millis()).await;
                }
            }
        }
    }

    #[task(binds = USB_OTG1, local = [poller])]
    fn log_over_usb(cx: log_over_usb::Context) {
        cx.local.poller.poll();
    }
}

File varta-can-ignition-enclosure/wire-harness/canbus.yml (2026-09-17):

connectors:
  Can0:
    type: M12-5
    subtype: female
    pinlabels: [Wake-up, On/Off, Gnd, CAN High, CAN Low]
    image:
      src: m12-5.png

  Can1:
    type: M12-5
    subtype: female
    pinlabels: [Wake-up, On/Off, Gnd, CAN High, CAN Low]
    image:
      src: m12-5.png

  Can2:
    type: M12-5
    subtype: female
    pinlabels: [Wake-up, On/Off, Gnd, CAN High, CAN Low]
    image:
      src: m12-5.png

  IgnitionSwitch:
    type: rocker
    pinlabels: [On/Off, Gnd]
    image:
      src: rocker-switch.png

  WagoOnOff:
    type: Wago
    subtype: female
    pincount: 4

  WagoGround:
    type: Wago
    subtype: female
    pincount: 4

  WagoCanHigh:
    type: Wago
    subtype: female
    pincount: 3

  WagoCanLow:
    type: Wago
    subtype: female
    pincount: 3

cables:

  Can0Wire:
    colors: [BN, YE, BK, GN, WH]
    wirecount: 5 # need to specify number of wires explicitly when using a color code
    gauge: 24 awg # accepts AWG or mm2 as unit
    show_equiv: true # auto-calculate AWG equivalent from metric gauge
    length: 10 cm
    shield: false
    #type: Serial

  Can1Wire:
    colors: [BN, YE, BK, GN, WH]
    wirecount: 5 # need to specify number of wires explicitly when using a color code
    gauge: 24 awg
    show_equiv: true # auto-calculate AWG equivalent from metric gauge
    length: 10 cm
    shield: false
    #type: Serial

  Can2Wire:
    colors: [BN, YE, BK, GN, WH]
    wirecount: 5 # need to specify number of wires explicitly when using a color code
    gauge: 24 awg
    show_equiv: true # auto-calculate AWG equivalent from metric gauge
    length: 10 cm
    shield: false
    #type: Serial

  IgnitionSwitchWire:
    colors: [YE, BK]
    gauge: 24 awg
    show_equiv: true # auto-calculate AWG equivalent from metric gauge
    length: 10 cm
    shield: false
    #type: Serial

connections:

  -
    - Can0: On/Off
    - Can0Wire: 2
    - WagoOnOff: 1
  -
    - Can1: On/Off
    - Can1Wire: 2
    - WagoOnOff: 2
  -
    - Can2: 2
    - Can2Wire: 2
    - WagoOnOff: 3
  -
    - IgnitionSwitch: On/Off
    - IgnitionSwitchWire: 1
    - WagoOnOff: 4

  -
    - Can0: 3
    - Can0Wire: 3
    - WagoGround: 1
  -
    - Can1: 3
    - Can1Wire: 3
    - WagoGround: 2
  -
    - Can2: 3
    - Can2Wire: 3
    - WagoGround: 3
  -
    - IgnitionSwitch: Gnd
    - IgnitionSwitchWire: 2
    - WagoGround: 4

  -
    - Can0: 4
    - Can0Wire: 4
    - WagoCanHigh: 1
  -
    - Can1: 4
    - Can1Wire: 4
    - WagoCanHigh: 2
  -
    - Can2: 4
    - Can2Wire: 4
    - WagoCanHigh: 3

  -
    - Can0: 5
    - Can0Wire: 5
    - WagoCanLow: 1
  -
    - Can1: 5
    - Can1Wire: 5
    - WagoCanLow: 2
  -
    - Can2: 5
    - Can2Wire: 5
    - WagoCanLow: 3

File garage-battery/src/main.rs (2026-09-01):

mod charger_deltaq_icl1500;
mod config;
mod controller;
mod pv_monitor;
mod types;
mod varta;

use clap::Parser;

#[derive(clap::Parser, Debug)]
#[command(version, about = "Garage battery management system")]
struct Args {
    #[arg(long, short = 'c', default_value = "config.toml")]
    config: String,
}

#[tokio::main]
async fn main() {
    let args = Args::parse();
    let cfg = config::load(&args.config);

    let auth_token = match std::fs::read_to_string(&cfg.envoy_auth_token_path) {
        Ok(t) => t.trim().to_string(),
        Err(e) => {
            println!(
                "cannot read auth token from '{}': {}",
                cfg.envoy_auth_token_path, e
            );
            std::process::exit(1);
        },
    };

    let (varta_tx, mut varta_rx) = tokio::sync::broadcast::channel::<varta::Message>(100);
    let varta_task = {
        let varta_can = cfg.varta_can_interface.clone();
        let varta_tx = varta_tx.clone();
        tokio::spawn(async move {
            varta::run(&varta_can, varta_tx).await;
        })
    };

    let (pv_tx, pv_rx) = tokio::sync::watch::channel::<Option<types::PvState>>(None);
    let pv_task = {
        let envoy_url = cfg.envoy_url.clone();
        tokio::spawn(async move {
            pv_monitor::run(&envoy_url, &auth_token, cfg.pv_poll_interval_secs, pv_tx).await;
        })
    };

    let (charger_cmd_tx, charger_cmd_rx) =
        tokio::sync::watch::channel::<Option<charger_deltaq_icl1500::ChargerCommand>>(None);
    let charger_task = {
        let charger_can = cfg.charger_can_interface.clone();
        tokio::spawn(async move {
            charger_deltaq_icl1500::run(
                &charger_can,
                cfg.charger_command_interval_secs,
                charger_cmd_rx,
            )
            .await;
        })
    };

    let controller_task = {
        let control_config = cfg.control.clone();
        let varta_rx = varta_tx.subscribe();
        tokio::spawn(async move {
            controller::run(control_config, varta_rx, pv_rx, charger_cmd_tx).await;
        })
    };

    loop {
        tokio::select! {
            // Wait for the user to hit Ctrl-C
            r = tokio::signal::ctrl_c() => {
                if let Err(e) = r {
                    panic!("failed to listen for ctrl-c: {e:?}");
                }
                println!("received Ctrl-C, shutting down");
                break;
            }

            varta_msg = varta_rx.recv() => {
                let Ok(varta_msg) = varta_msg else {
                    println!("error reading varta msg: {varta_msg:?}");
                    continue;
                };
                match varta_msg {
                    crate::varta::Message::Msg(msg) => println!("varta: {}", msg),
                    _ => {},
                }
            }
        }
    }

    varta_task.abort();
    pv_task.abort();
    controller_task.abort();

    charger_task.abort();
    charger_deltaq_icl1500::shutdown(&cfg.charger_can_interface).await;

    println!("shutdown: complete");
}

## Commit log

2025-04-05 README: add some wire harness info
2025-04-16 README: add notes on charger
2025-04-17 add some Delta Q ICL-1500-058V charger docs
2025-04-17 reorg battery info
2025-04-17 move charger docs
2025-04-17 add a program to control the charger
2025-04-17 add a description of ABS battery cell connections
2025-04-18 charger: allow overriding battery temperature and soc
2025-04-18 add battery dbc
2025-04-18 better battery pack control over CAN
2025-04-19 start adding battery interface code
2025-04-19 dbc codegen
    This includes some inconsequential whitespace tweaks to the battery dbc
    to make it palatable to dbc-codegen.
2025-04-21 battery dbc: fix some signal limits
    8-bit unsigned signals only go up to 255, not 65535.
2025-04-21 battery: decode & dump battery CAN packets
2025-04-21 README: charger gets hot and doesn't turn on its fan
2025-04-22 charger: remove dead code
2025-04-22 charger: pass explicit parameters in to send_command()
    Don't just pass in the whole command-line Args struct and have the
    function pick out the things it wants.
2025-04-22 charger: shut down the charger on ^C
2025-04-26 README: charger CAN info
2025-04-26 README: the charger fan comes on eventually
2025-04-26 add a battery tui
2025-04-26 fix some compile warnings that crept in
    [app.rs]
2025-04-27 note multi-module packs charge/discharge behavior
2025-04-27 better demo of charge/discharge behavior
2025-04-28 start the app in None mode, not Sleep
    This way we get good telemetry right away, but the HV bus is still
    powered down.
2025-12-17 add info on battery HV terminals
2025-12-18 battery: update build script for new dbc-codegen
2025-12-18 charger: update build script for new dbc-codegen
2025-12-18 add teensy-battery-controller
    This is based on the teensy4-rs template:
    <https://github.com/mciantyre/teensy4-rs-template>
2025-12-20 teensy-battery-controller: read CAN packets from battery
2025-12-21 add a pic of the teensy 4 back
2025-12-21 teensy: start adding a "power" button input
2025-12-21 teensy: decode & log CAN packets
2025-12-21 teensy: add CAN tx to keep battery on
2025-12-21 teensy: add modal behavior and battery Discharge/Sleep control
2025-12-22 teensy: debounce the power button consistently
2025-12-22 teensy: only send one Sleep command
2025-12-22 add a document describing the teensy "USB battery" system
2025-12-23 teensy: rename the firware to "teensy-battery-controller"
    Not "hello-world" lol
2025-12-23 teensy: add second CAN, decode Delta Q packets
2025-12-23 teensy: handle switching from Sleep to Discharge
    This is useful when the teensy is powered over USB and thus survives
    the battery going to Sleep.
2026-01-16 WIP: add enclosure
    [box.FCStd, faceplate.FCStd]
2026-06-27 teensy: better debug logging
2026-06-29 charger: cargo update everything, fix dbc-codegen build script to match
2026-06-29 charger: add Cargo.lock
2026-06-29 battery: cargo update everything, fix code to match
    [app.rs]
2026-06-29 battery: add Cargo.lock
2026-08-03 move deltaq charger code out to a separate repo
2026-08-10 bump deltaq-charger submodule
2026-08-10 add garage battery controller
2026-08-15 garage-battery: rename "charge_controller" to "charger", simpler
2026-08-15 garage-battery: minor code cleanup in main
2026-08-15 garage-battery: minor code cleanup in varta task
2026-08-15 garage-battery: better varta message passing
2026-08-15 garage-battery: minor charger cleanups
2026-08-15 garage-battery: get rid of config.default_charge_current
2026-08-15 garage-battery: cargo fmt and comments
2026-08-15 garage-battery: cargo update
2026-08-15 garage-battery: minor fixes in controller
2026-09-01 rename abs enclosure
    [box.FCStd, faceplate.FCStd]
2026-09-01 add an enclosure for the precharge circuit
    [precharge-enclosure.FCStd, precharge-lid.3mf, precharge-plate.3mf]
2026-09-01 add enclosure & wireviz for the Varta CAN/Ignition wiring
    [can-ignition-enclosure.FCStd, can-ignition-lid.3mf, can-ignition-plate.3mf]
2026-09-01 garage-battery: refactor controller to support multiple control algorithms
2026-09-01 garage-battery: add a "Hold xx.xxx% SoC" controller
    I hope this will be useful for conditioning battery modules to join
    together into a pack, they should be near the same SoC.
2026-09-01 garage-battery: integration with udev & systemd
2026-09-01 garage-battery: fix varta open-loop requested charge voltage
2026-09-01 garage-battery: add a systemd service file for the controller
2026-09-01 garage-battery: rename "charger" to "charger_deltaq_icl1500" for clarity
2026-09-02 varta-can-ignition-enclosure: fix a hole that got plugged up
    [can-ignition-enclosure.FCStd, can-ignition-plate.3mf]
2026-09-04 update to new version of deltaq-charger
    Still only supports ICL1500 for now, XV3300 coming soon.
2026-09-17 garage battery: helpful comment in the systemd.network files
2026-09-17 minor tweaks to precharge enclosure
    [precharge-enclosure.FCStd, precharge-plate.3mf]
2026-09-17 varta wire harness improvements
2026-09-24 garage-battery systemd service cleanup
2026-10-13 garage-battery controller: better debug output
2026-10-13 garage-battery controller: charger is off unless commanded on
2026-10-13 garage-battery controller: simplify AC current logic
2026-10-13 garage battery: better xv3300 control, this seems to work
2026-10-13 garage-battery: config for xv3300
2026-10-13 garage-battery controller: rename a variable for consistency
2026-10-13 add a grafana dashboard to show the battery behavior
2026-10-28 use a public repo for the deltaq-charger submodule
